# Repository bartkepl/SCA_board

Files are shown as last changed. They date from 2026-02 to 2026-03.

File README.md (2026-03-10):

# SCA (Standalone Connector Adapter)
Standalone Connector Adapter for other 3U eurocards. Converts DIN41612 connector to USB, USB(UART converter), ETHERNET and RS485

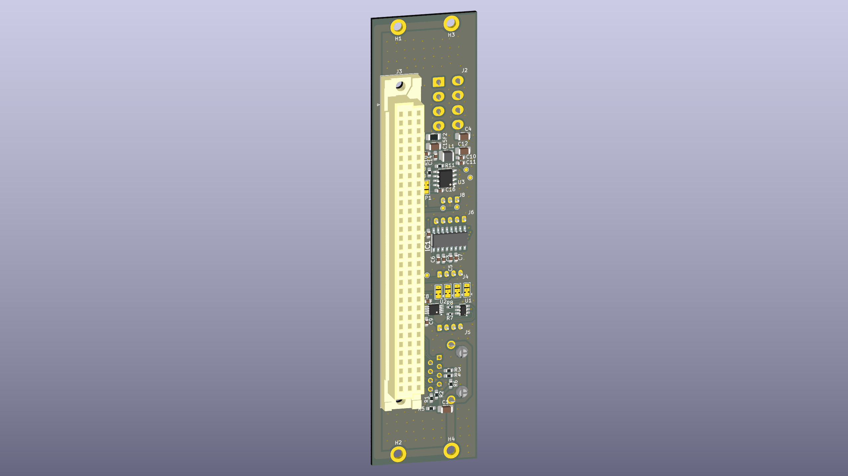
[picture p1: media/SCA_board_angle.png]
Standalone Connector Adapter board


---
## Status : WIP

- First revision of schematic and PCB is done. 
- Board for testing other boards and their software
  
---

## Features:
- 4x JST PH for USB, USB-UART, RS486 and RS232 
- 10/100/1000 Ethernet connector 
- 3U 6TE eurocard IEEE 1101.1-1998 format (128x30,1 mm)

## License and Contribution

[MIT License](/LICENSE)

Open to contributions in both software and hardware!

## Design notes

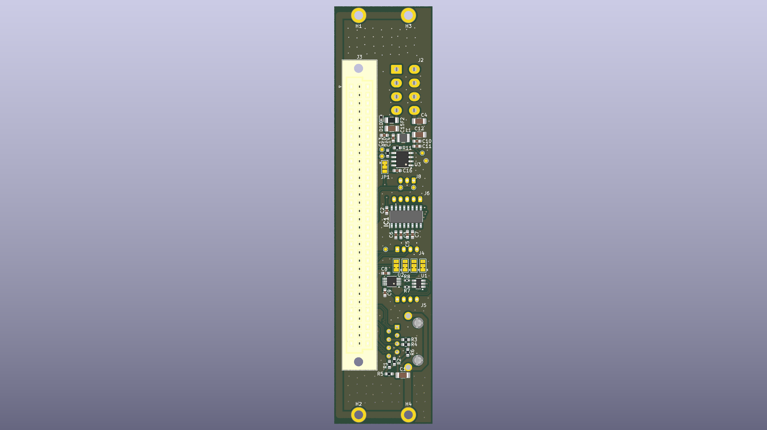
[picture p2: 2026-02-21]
media/SCA_board_front.png

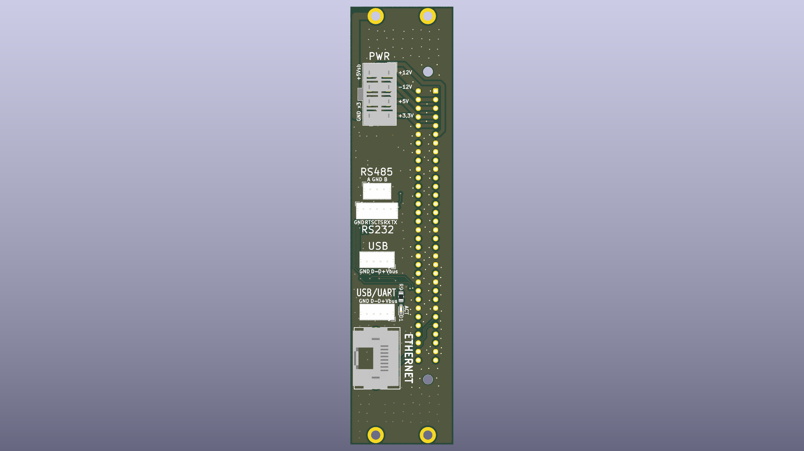
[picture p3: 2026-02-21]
media/SCA_board_back.png

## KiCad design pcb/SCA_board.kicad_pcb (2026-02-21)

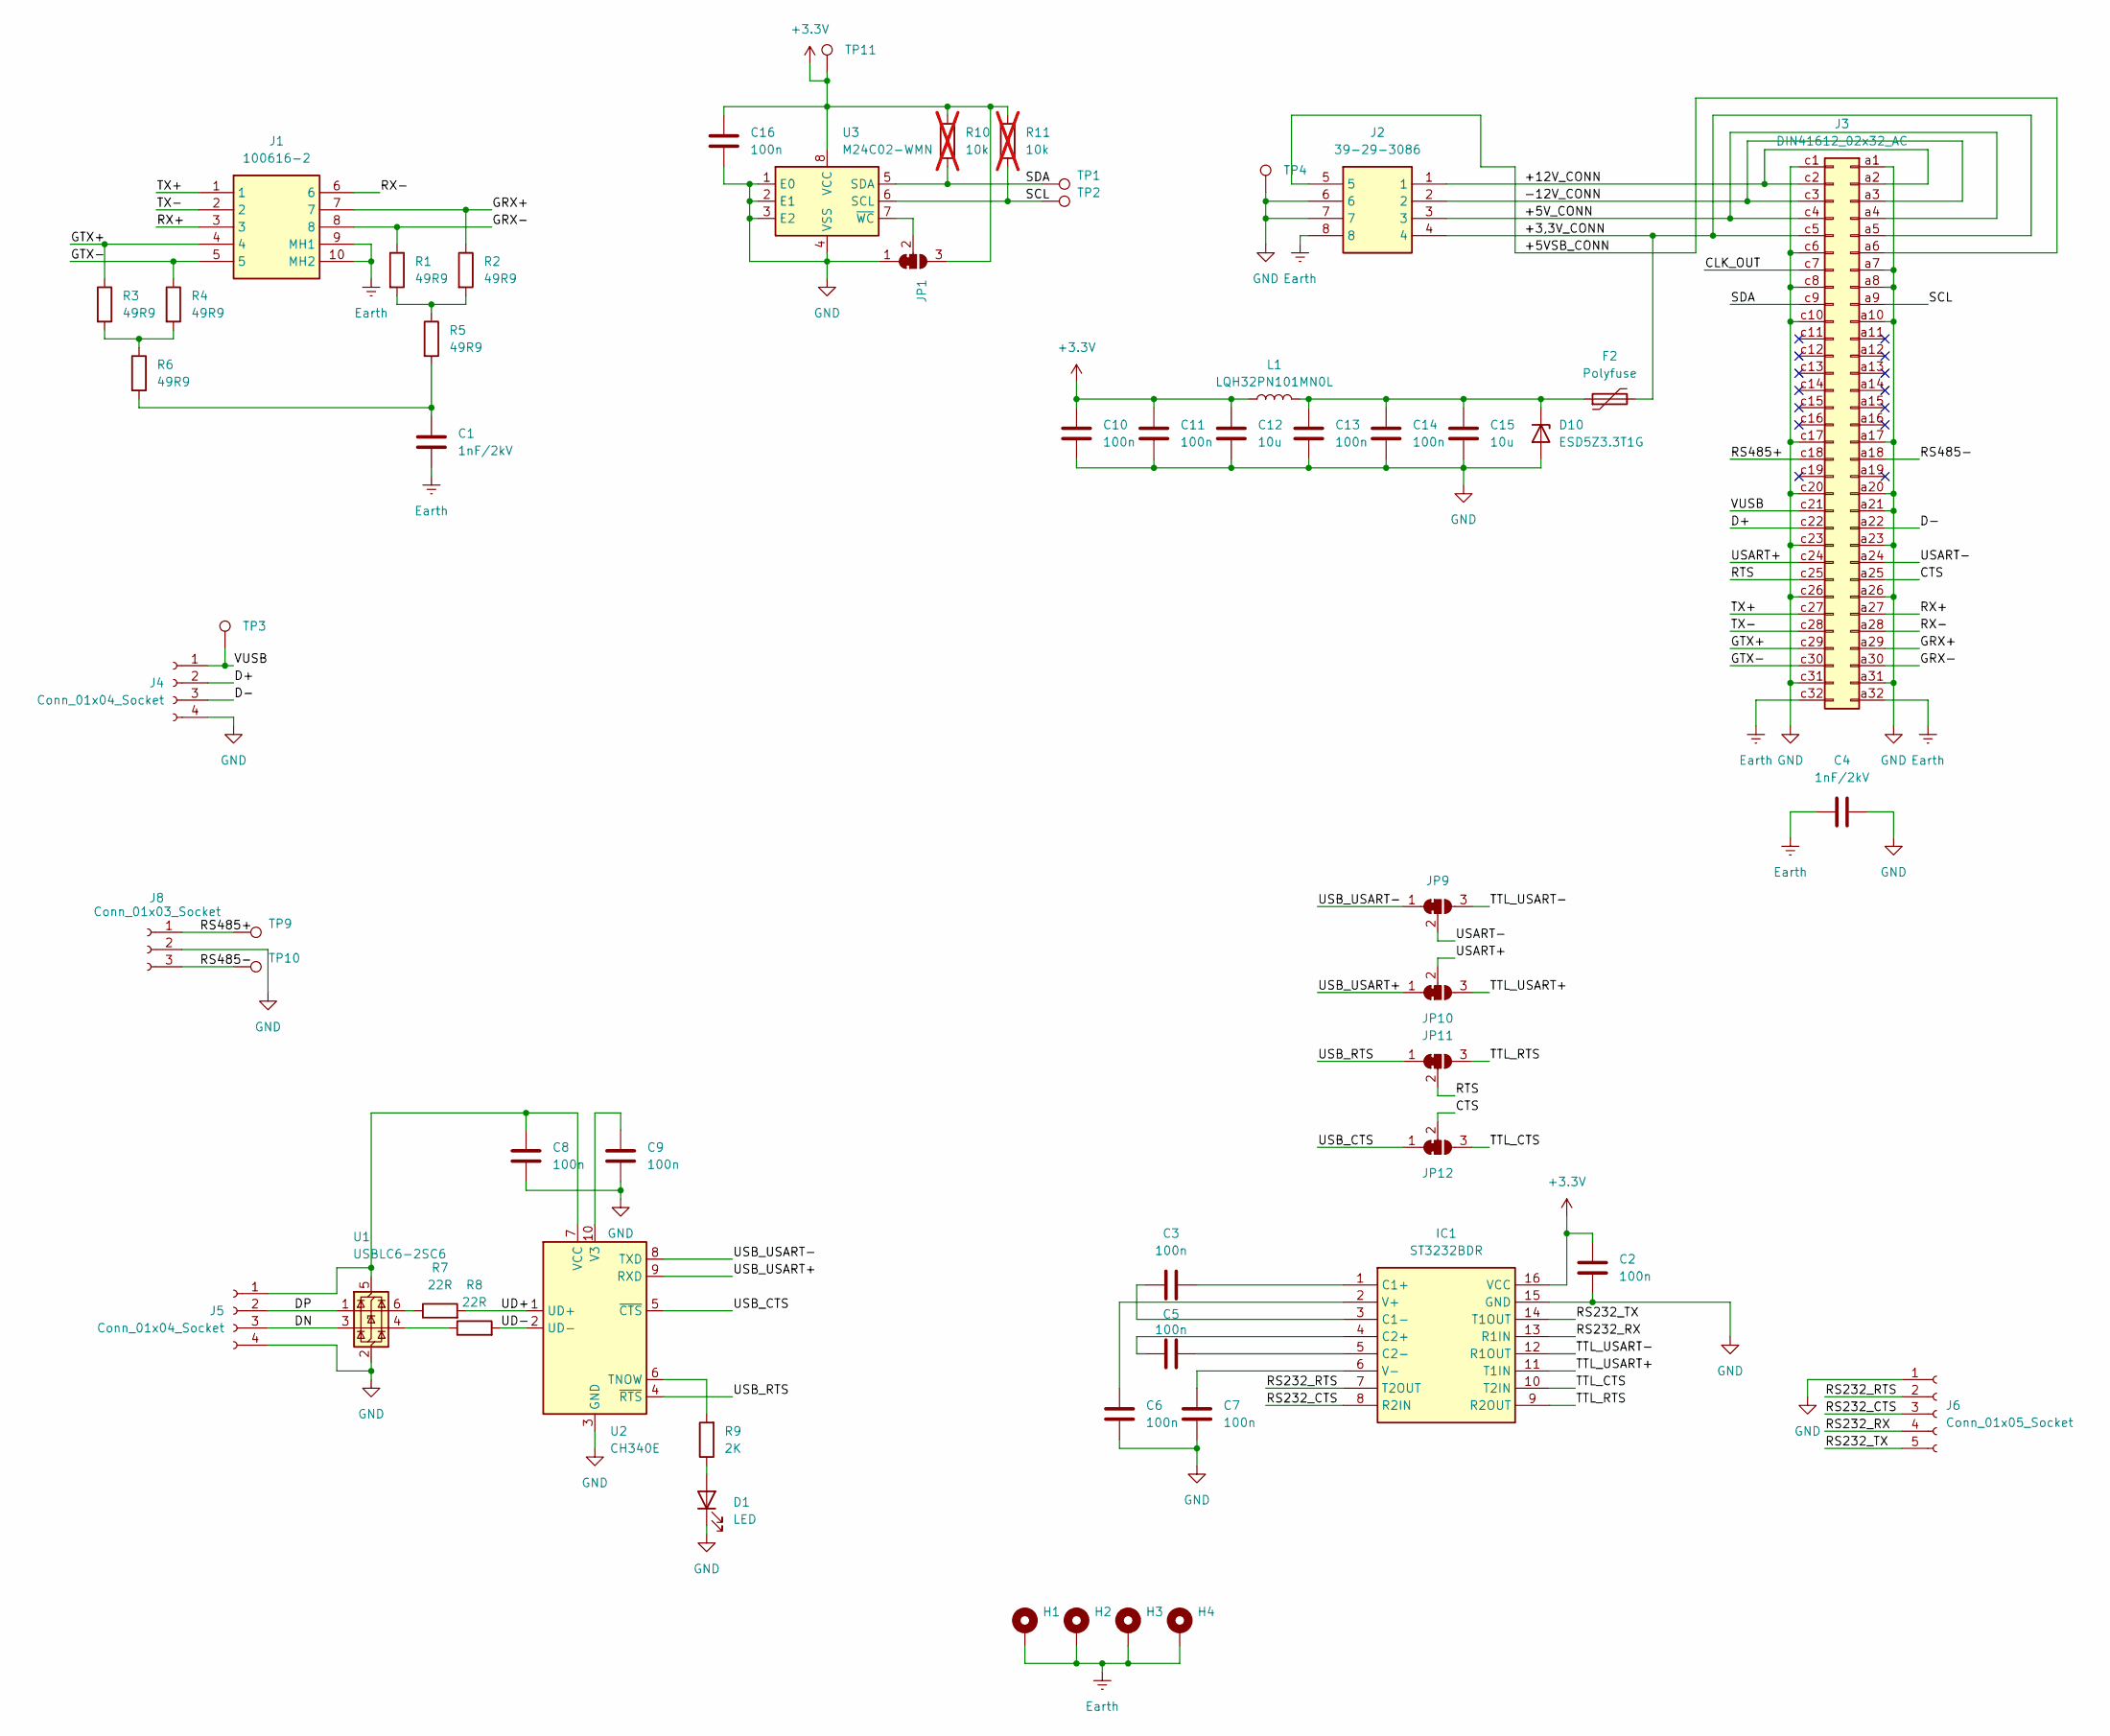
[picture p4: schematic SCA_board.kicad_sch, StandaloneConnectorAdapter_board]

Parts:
C1, C4: 1nF/2kV; C_1206_3216Metric_Pad1.33x1.80mm_HandSolder
C2, C3, C5, C6, C7, C8, C9, C10, C11, C13, C14, C16: 100n; C_0603_1608Metric_Pad1.08x0.95mm_HandSolder
C12, C15: 10u; C_1206_3216Metric_Pad1.33x1.80mm_HandSolder
D1: LED; LED_0603_1608Metric_Pad1.05x0.95mm_HandSolder
D10: ESD5Z3.3T1G; D_SOD-523
F2: Polyfuse; Fuse_1206_3216Metric_Pad1.42x1.75mm_HandSolder
H1, H2, H3, H4: MountingHole_Pad; MountingHole_2.7mm_M2.5_DIN965_Pad
IC1: ST3232BDR; SOIC127P600X175-16N; Manufacturer_Part_Number ST3232BDR
J1: 100616-2; 1006162; Manufacturer_Part_Number 100616-2
J2: 39-29-3086; Molex_Mini-Fit_Jr_5566-08A_2x04_P4.20mm_Vertical; Manufacturer_Part_Number 39-29-3086
J3: DIN41612_02x32_AC; DIN41612_C_2x32_Female_Vertical_THT
J4, J5: Conn_01x04_Socket; JST_PH_B4B-PH-K_1x04_P2.00mm_Vertical
J6: Conn_01x05_Socket; JST_PH_B5B-PH-K_1x05_P2.00mm_Vertical
J8: Conn_01x03_Socket; JST_PH_B3B-PH-K_1x03_P2.00mm_Vertical
JP1, JP9, JP10, JP11, JP12: SolderJumper_3_Bridged12; SolderJumper-3_P1.3mm_Bridged12_Pad1.0x1.5mm
L1: LQH32PN101MN0L; L_1210_3225Metric
R1, R2, R3, R4, R5, R6: 49R9; R_0603_1608Metric_Pad0.98x0.95mm_HandSolder
R7, R8: 22R; R_0402_1005Metric_Pad0.72x0.64mm_HandSolder
R9: 2K; R_0805_2012Metric_Pad1.20x1.40mm_HandSolder
R10, R11: 10k; R_0603_1608Metric_Pad0.98x0.95mm_HandSolder; not fitted
TP1, TP2, TP3, TP4, TP9, TP10, TP11: TestPoint; TestPoint_Pad_D1.0mm
U1: USBLC6-2SC6; SOT-23-6_Handsoldering
U2: CH340E; MSOP-10_3x3mm_P0.5mm
U3: M24C02-WMN; SOIC-8_3.9x4.9mm_P1.27mm

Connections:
+3.3V: C2.1, C10.1, C11.1, C12.1, C16.2, IC1.16 (VCC), JP1.3 (B), L1.1, R10.2, R11.2, TP11.1, U3.8 (VCC)
/+3,3V_CONN: F2.2, J2.4, J3.a5, J3.c5
/+5VSB_CONN: J2.5, J3.a6
/+5V_CONN: J2.3, J3.a4, J3.c4
/+12V_CONN: J2.1, J3.a2, J3.c2
/-12V_CONN: J2.2, J3.a3, J3.c3
/CLK_OUT: J3.c7
/CTS: J3.a25, JP12.2 (C)
/D+: J3.c22, J4.2
/D-: J3.a22, J4.3
/DN: J5.3, U1.3 (I/O2)
/DP: J5.2, U1.1 (I/O1)
/GRX+: J1.7, J3.a29, R2.1
/GRX-: J1.8, J3.a30, R1.1
/GTX+: J1.4, J3.c29, R3.1
/GTX-: J1.5, J3.c30, R4.1
/RS232_CTS: IC1.8 (R2IN), J6.3
/RS232_RTS: IC1.7 (T2OUT), J6.2
/RS232_RX: IC1.13 (R1IN), J6.4
/RS232_TX: IC1.14 (T1OUT), J6.5
/RS485+: J3.c18, J8.1, TP9.1
/RS485-: J3.a18, J8.3, TP10.1
/RTS: J3.c25, JP11.2 (C)
/RX+: J1.3, J3.a27
/RX-: J1.6, J3.a28
/SCL: J3.a9, R11.1, TP2.1, U3.6 (SCL)
/SDA: J3.c9, R10.1, TP1.1, U3.5 (SDA)
/TTL_CTS: IC1.10 (T2IN), JP12.3 (B)
/TTL_RTS: IC1.9 (R2OUT), JP11.3 (B)
/TTL_USART+: IC1.11 (T1IN), JP10.3 (B)
/TTL_USART-: IC1.12 (R1OUT), JP9.3 (B)
/TX+: J1.1, J3.c27
/TX-: J1.2, J3.c28
/UD+: R7.2, U2.1 (UD+)
/UD-: R8.2, U2.2 (UD-)
/USART+: J3.c24, JP10.2 (C)
/USART-: J3.a24, JP9.2 (C)
/USB_CTS: JP12.1 (A), U2.5 (~CTS)
/USB_RTS: JP11.1 (A), U2.4 (~RTS)
/USB_USART+: JP10.1 (A), U2.9 (RXD)
/USB_USART-: JP9.1 (A), U2.8 (TXD)
/VUSB: J3.c21, J4.1, TP3.1
Earth: C1.2, C4.1, H1.1, H2.1, H3.1, H4.1, J1.9 (MH1), J1.10 (MH2), J2.8, J3.a32, J3.c32
GND: C2.2, C4.2, C6.1, C7.1, C8.1, C9.1, C10.2, C11.2, C12.2, C13.2, C14.2, C15.2, C16.1, D1.1 (K), D10.2 (A), IC1.15 (GND), J2.6, J2.7, J3.a1, J3.a7, J3.a8, J3.a10, J3.a17, J3.a20, J3.a21, J3.a23, J3.a26, J3.a31, J3.c1, J3.c6, J3.c8, J3.c10, J3.c17, J3.c20, J3.c23, J3.c26, J3.c31, J4.4, J5.4, J6.1, J8.2, JP1.1 (A), TP4.1, U1.2 (GND), U2.3 (GND), U3.1 (E0), U3.2 (E1), U3.3 (E2), U3.4 (VSS)
unnamed: C1.1, R5.2, R6.2
unnamed: D1.2 (A), R9.1
unnamed: C13.1, C14.1, C15.1, D10.1 (K), F2.1, L1.2
unnamed: C3.2, IC1.1 (C1+)
unnamed: C3.1, IC1.3 (C1-)
unnamed: C5.1, IC1.4 (C2+)
unnamed: C5.2, IC1.5 (C2-)
unnamed: C6.2, IC1.2 (V+)
unnamed: C7.2, IC1.6 (V-)
unnamed: C8.2, J5.1, U1.5 (VBUS), U2.7 (VCC)
unnamed: JP1.2 (C), U3.7 (~WC)
unnamed: R1.2, R2.2, R5.1
unnamed: R3.2, R4.2, R6.1
unnamed: R7.1, U1.6 (I/O1)
unnamed: R8.1, U1.4 (I/O2)
unnamed: R9.2, U2.6 (TNOW)
unnamed: C9.2, U2.10 (V3)

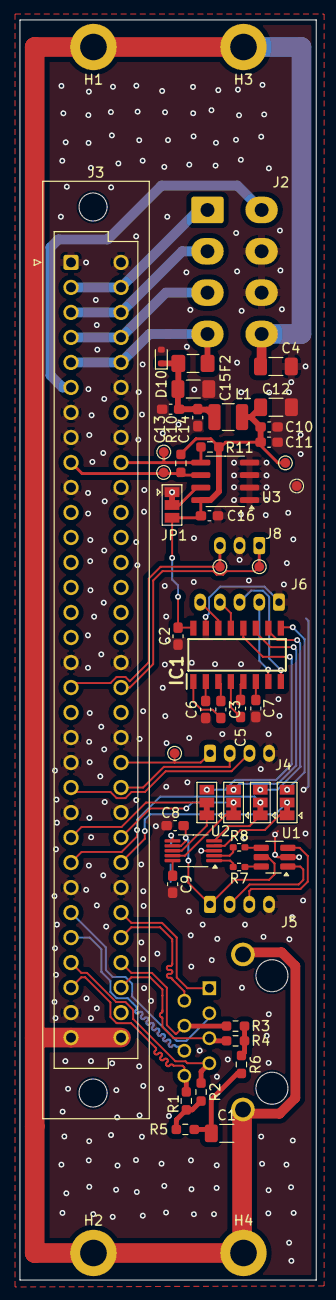
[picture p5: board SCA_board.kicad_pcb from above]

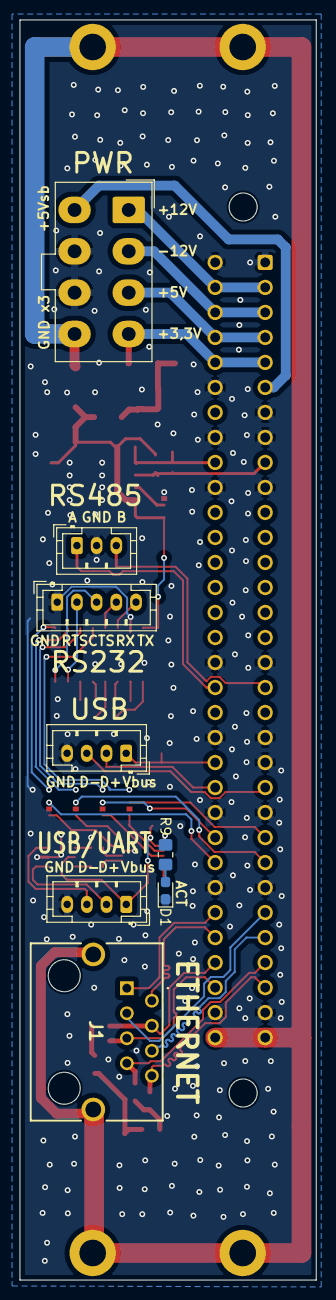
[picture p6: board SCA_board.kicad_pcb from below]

Board: 2 copper layers, 30.1 x 128.0 mm, 58 parts (8 on the bottom side), 60 nets.

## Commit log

2026-02-12 First board revision for testing others boards
    [SCA_board-CuBottom.gbr, SCA_board-CuTop.gbr, SCA_board-EdgeCuts.gbr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]
2026-02-14 Added i2c config eeprom and testpoints
    [SCA_board-CuBottom.gbr, SCA_board-CuTop.gbr, SCA_board-EdgeCuts.gbr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]
2026-02-21 Changed file organization
    [SCA_board-CuBottom.gbr, SCA_board-CuTop.gbr, SCA_board-EdgeCuts.gbr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]
2026-02-21 Connector and layout change
    [SCA_board.kicad_pcb, SCA_board.kicad_sch]
2026-02-21 Added stitching
    [SCA_board.kicad_pcb]
2026-02-21 Repaired stitching
    [SCA_board.kicad_pcb]
